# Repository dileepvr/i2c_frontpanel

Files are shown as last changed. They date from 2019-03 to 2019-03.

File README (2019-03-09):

---------------------------------------------------------------
i2c Frontpanel with 7-segment digits, pushbuttons, and two LEDs
---------------------------------------------------------------

Dumb frontpanel for small projects. Can be daisy-chained as long as
you do not populate all (except one) of the i2c pull-up resistors.

Powered by ATTiny88.

4-pin inter-header spacing is arduino compatible.

The PCBnew files are:

* 1x7seg_4btn.kicad_pcb (One 7-segment digit, four buttons, two LEDs)
* 2x7seg_4btn.kicad_pcb (Two 7-segment digits, four buttons, two LEDs)
* 4x7seg_6btn.kicad_pcb (Four 7-segment digits, six buttons, two LEDs)
* 4btn.kicad_pcb (Four buttons, two LEDs)
* 6btn.kicad_pcb (Six buttons, two LEDs)
* i2c_frontpanel.kicad_pcb (Same as 4x7seg_6btn.kicad_pcb)

Gerber files included for 4x7seg_6btn.kicad_pcb and
1x7seg_4btn.kicad_pcb designs.

The "firmware" folder contains the firmware for the ATTiny88.
Uses the ATTinyCore library: https://github.com/SpenceKonde/ATTinyCore

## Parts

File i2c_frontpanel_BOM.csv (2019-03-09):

Reference | Quantity | Value | Footprint | Part function | Mouser part # | Mouser link
AFF1 AFF2 AFF3 AFF4 | 4 | 7SEGMENTS | i2c_frontpanel:7seg_LTS_4817CKR_P | 7 segment digit | 859-LTS-4817CKR-P | https://www.mouser.com/ProductDetail/lite-on/lts-4817ckr-p/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
C1 C2 C3 C4 C5 C6 C7 C8 | 8 | 0.1uF | Capacitors_SMD:C_1206 | Capacitor | 710-885012208009 | https://www.mouser.com/ProductDetail/wurth-electronics/885012208009/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
CON1 | 1 | AVR-ISP-6-DR | Pin_Headers:Pin_Header_Straight_SMT_02x03 | 2x3 vertical smd header pins | 538-15-91-2060 | https://www.mouser.com/ProductDetail/molex/15-91-2060/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
D1 D2 | 2 | LED | LEDs:LED_1206 | Colored status LEDs | 743-S126ATG | https://www.mouser.com/ProductDetail/inolux/in-s126atg/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
IC1 | 1 | ATTINY88-A | Housings_QFP:TQFP-32_7x7mm_Pitch0.8mm | ATTINY88 Microcontroller | 556-ATTINY88-AUR | https://www.mouser.com/ProductDetail/microchip/attiny88-aur/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
Q1 Q2 Q3 Q4 Q5 Q6 | 6 | 2N7002 | TO_SOT_Packages_SMD:SOT-23 | N-MOSFET | 512-2N7002L | https://www.mouser.com/ProductDetail/on-semiconductor/2n7002l/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
R20 R21 | 2 | 4.7k | Resistors_SMD:R_1206 | Resistor | 603-RC0402FR-104K7L | https://www.mouser.com/ProductDetail/yageo/rc0402fr-104k7l/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
R22 R23 R24 R25 R26 R27 R28 R29 R30 R31 R32 R33 R34 R35 R36 R37 R38 R39 R40 R41 R42 R43 R44 R45 R46 R47 R48 R49 R50 R51 R52 R53 R54 R55 | 34 | 470 | Resistors_SMD:R_1206 | Resistor | 603-RC0402FR-13200RL | https://www.mouser.com/ProductDetail/yageo/rc0402fr-13200rl/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
R10 R11 R18 R19 R7 R8 | 6 | 100 | Resistors_SMD:R_1206 | Resistor | 603-RC0402FR-13200RL | https://www.mouser.com/ProductDetail/yageo/rc0402fr-13200rl/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
R1 R12 R13 R14 R15 R16 R17 R2 R3 R4 R5 R6 R9 | 13 | 10k | Resistors_SMD:R_1206 | Resistor | 667-ERJ-8ENF1002V | https://www.mouser.com/ProductDetail/panasonic/erj-8enf1002v/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
U1 | 1 | 74HC14D_653 | SMD_Packages:SOIC-14_N | Hex inverter buffer for debouncing | 771-74HC14D-T | https://www.mouser.com/ProductDetail/nexperia/74hc14d653/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
U10 U11 U12 U13 | 4 | MC14543B | SMD_Packages:SO-16-N | BCD-to-7-segment decoder | 863-MC14543BDR2G | https://www.mouser.com/ProductDetail/on-semiconductor/mc14543bdr2g/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
U2 U3 U4 U5 U6 U7 | 6 | SW_SPST | Resistors_SMD:R_2816 | Pushbuttons | 688-SKPSAAE010 | https://www.mouser.com/ProductDetail/alps/skpsaae010/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
U8 U9 | 2 | I2C_4PINS | Pin_Headers:Pin_Header_Straight_1x04 | Header pins | 649-68001-236HLF | https://www.mouser.com/ProductDetail/fci-amphenol/68001-236hlf/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

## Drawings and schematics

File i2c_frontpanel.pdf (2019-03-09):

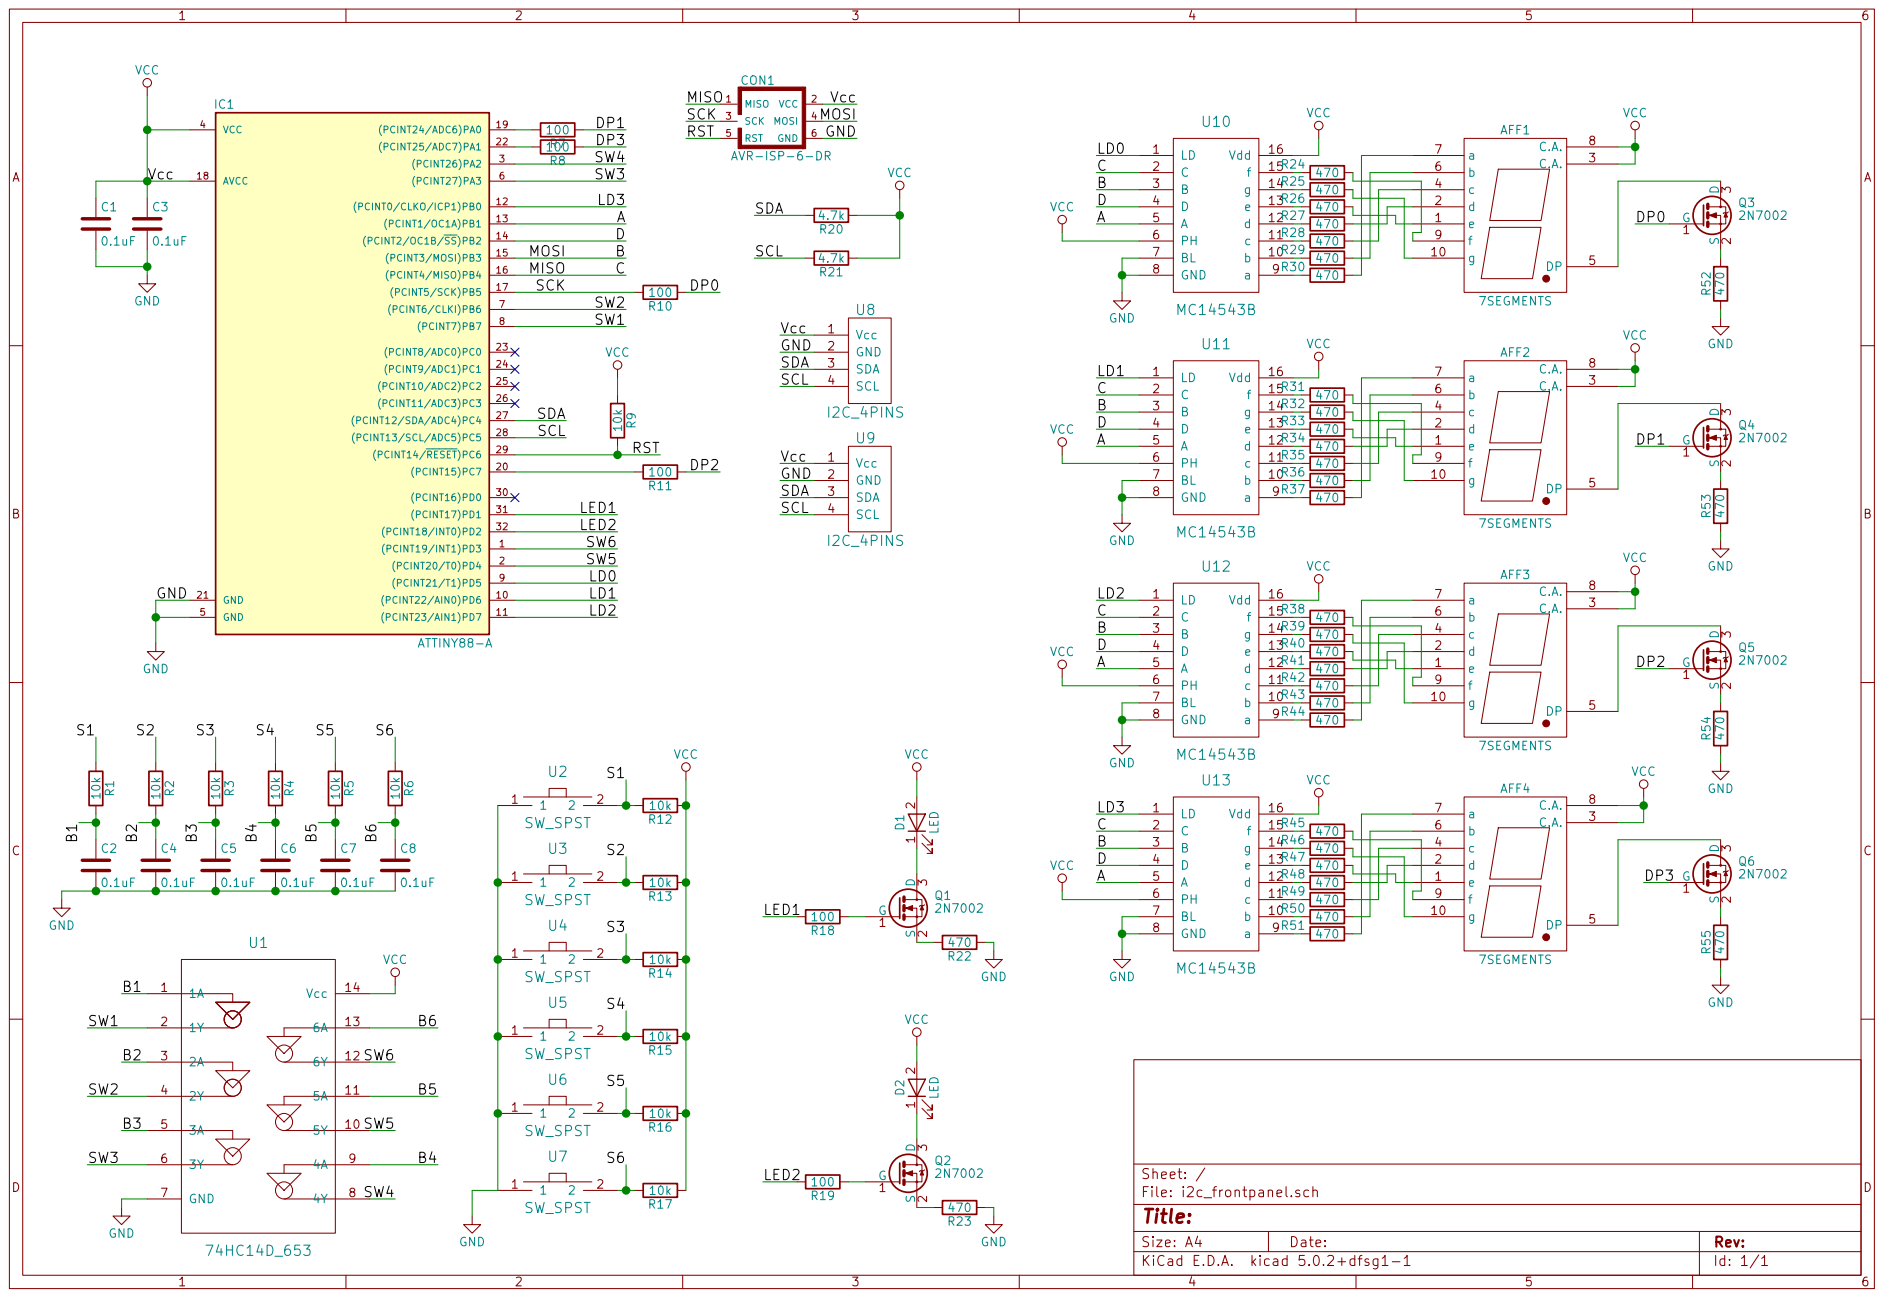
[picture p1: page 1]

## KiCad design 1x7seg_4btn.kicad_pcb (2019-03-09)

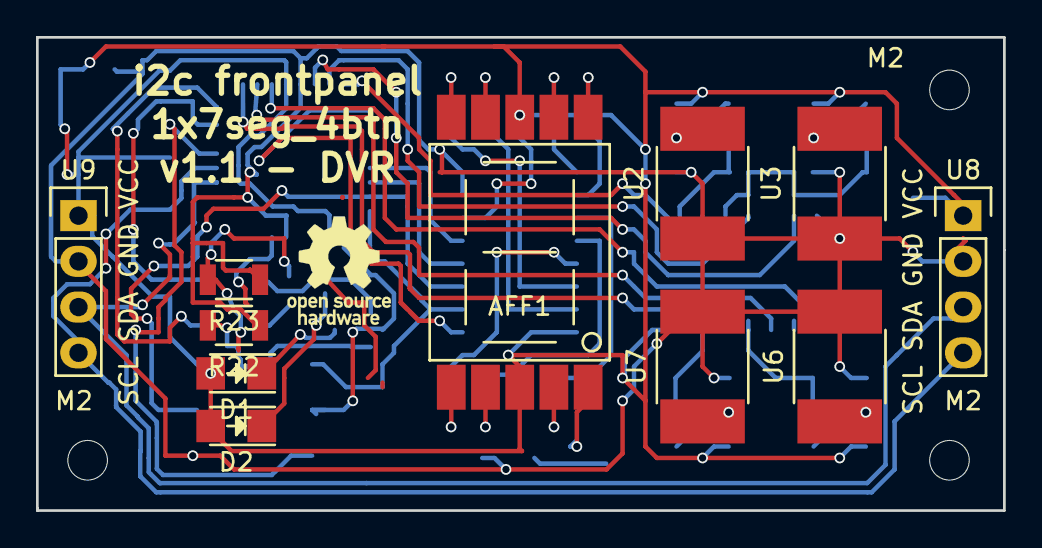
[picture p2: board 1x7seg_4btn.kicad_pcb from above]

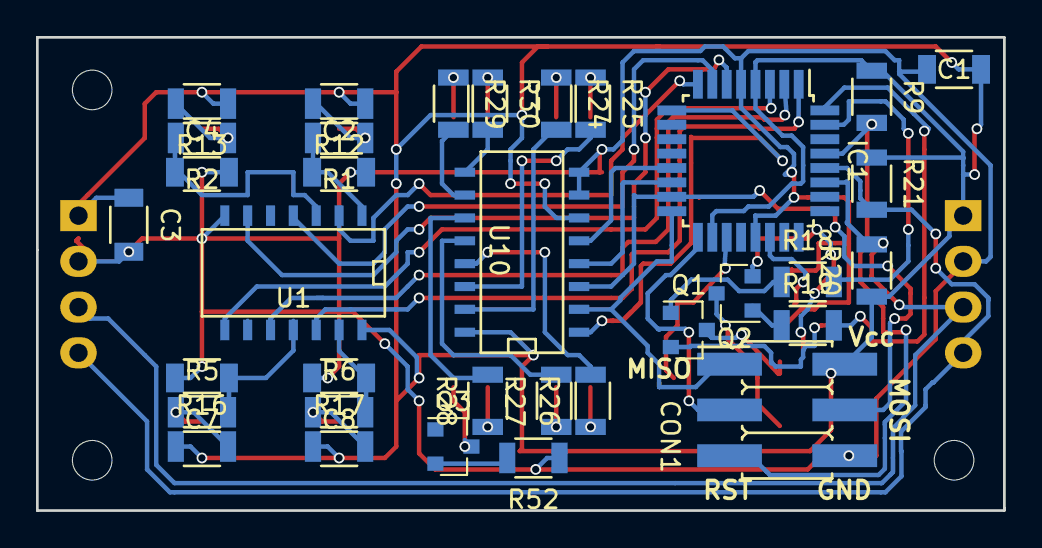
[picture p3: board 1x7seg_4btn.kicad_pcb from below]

Board: 2 copper layers, 53.7 x 26.3 mm, 45 parts (34 on the bottom side), 49 nets.

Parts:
AFF1: 7SEGMENTS; 7seg_LTS_4817CKR_P
C1, C2, C3, C4, C7, C8: 0.1uF; C_1206
CON1: AVR-ISP-6-DR; Pin_Header_Straight_SMT_02x03
D1, D2: LED; LED_1206
IC1: ATTINY88-A; TQFP-32_7x7mm_Pitch0.8mm
Q1, Q2, Q3: 2N7002; SOT-23
R1, R2, R5, R6, R9, R12, R13, R16, R17: 10k; R_1206
R18, R19: 100; R_1206
R20, R21: 4.7k; R_1206
R22, R23, R24, R25, R26, R27, R28, R29, R30, R52: 470; R_1206
U1: 74HC14D_653; SOIC-14_N
U2, U3, U6, U7: SW_SPST; R_2816
U8, U9: SCL SDA GND VCC; Pin_Header_Straight_1x04
U10: MC14543B; SO-16-N

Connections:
/A: IC1.13, U10.5
/B: CON1.4, IC1.15, U10.3
/B1: C2.1, R1.2, U1.1
/B2: C4.1, R2.2, U1.3
/B5: C7.1, R5.2, U1.11
/B6: C8.1, R6.2, U1.13
/C: CON1.1, IC1.16, U10.2
/D: IC1.14, U10.4
/LD0: IC1.9, U10.1
/LED1: IC1.31, R18.2
/LED2: IC1.32, R19.2
/RST: CON1.5, IC1.29, R9.2
/S1: R1.1, R12.2, U2.2
/S2: R2.1, R13.2, U3.2
/S5: R5.1, R16.2, U6.2
/S6: R6.1, R17.2, U7.2
/SCK: CON1.3, IC1.17
/SCL: IC1.28, R21.2, U8.4, U9.4
/SDA: IC1.27, R20.2, U8.3, U9.3
/SW1: IC1.8, U1.2
/SW2: IC1.7, U1.4
/SW3: IC1.6, U1.6
/SW4: IC1.3, U1.8
/SW5: IC1.2, U1.10
/SW6: IC1.1, U1.12
GND: C1.2, C2.2, C3.2, C4.2, C7.2, C8.2, CON1.6, IC1.5, IC1.21, R22.1, R23.1, R52.1, U1.7, U2.1, U3.1, U6.1, U7.1, U8.2, U9.2, U10.7, U10.8
unnamed: AFF1.1, R26.1
unnamed: AFF1.2, R27.1
unnamed: AFF1.4, R28.1
unnamed: AFF1.5, Q3.3
unnamed: AFF1.6, R29.1
unnamed: AFF1.7, R30.1
unnamed: AFF1.9, R24.1
unnamed: AFF1.10, R25.1
unnamed: D1.1, Q1.3
unnamed: D2.1, Q2.3
unnamed: Q1.1, R18.1
unnamed: Q1.2, R22.2
unnamed: Q2.1, R19.1
unnamed: Q2.2, R23.2
unnamed: Q3.2, R52.2
unnamed: R24.2, U10.15
unnamed: R25.2, U10.14
unnamed: R26.2, U10.13
unnamed: R27.2, U10.12
unnamed: R28.2, U10.11
unnamed: R29.2, U10.10
unnamed: R30.2, U10.9
VCC: AFF1.3, AFF1.8, C1.1, C3.1, CON1.2, D1.2, D2.2, IC1.4, IC1.18, R9.1, R12.1, R13.1, R16.1, R17.1, R20.1, R21.1, U1.14, U8.1, U9.1, U10.6, U10.16

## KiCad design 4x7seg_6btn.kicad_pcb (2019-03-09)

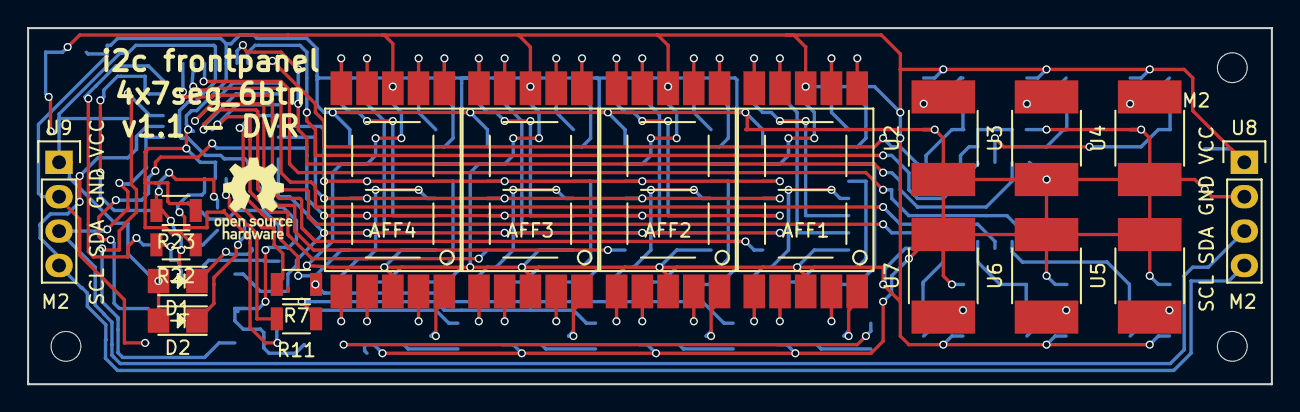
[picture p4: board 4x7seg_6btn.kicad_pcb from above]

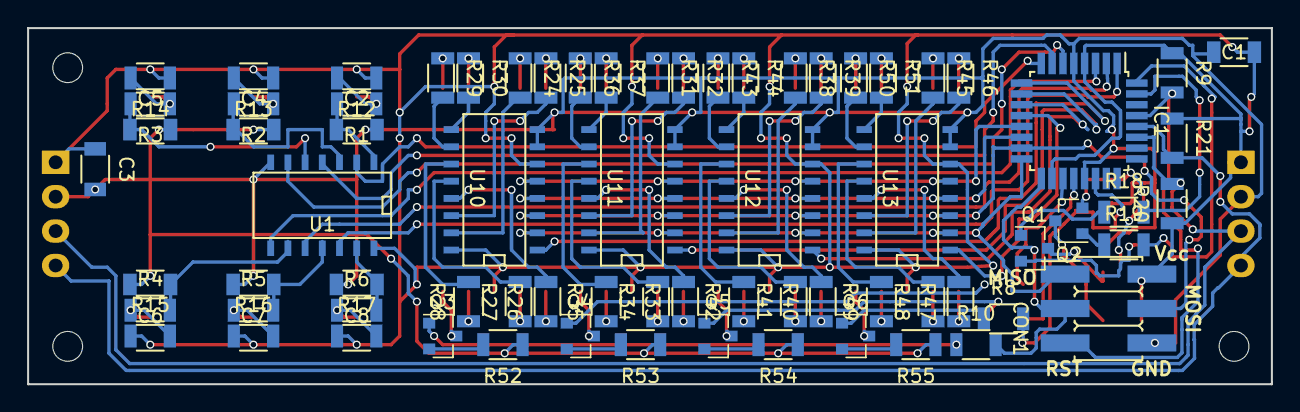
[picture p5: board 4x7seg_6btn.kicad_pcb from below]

Board: 2 copper layers, 91.8 x 26.3 mm, 90 parts (72 on the bottom side), 111 nets.

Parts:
AFF1, AFF2, AFF3, AFF4: 7SEGMENTS; 7seg_LTS_4817CKR_P
C1, C2, C3, C4, C5, C6, C7, C8: 0.1uF; C_1206
CON1: AVR-ISP-6-DR; Pin_Header_Straight_SMT_02x03
D1, D2: LED; LED_1206
IC1: ATTINY88-A; TQFP-32_7x7mm_Pitch0.8mm
Q1, Q2, Q3, Q4, Q5, Q6: 2N7002; SOT-23
R1, R2, R3, R4, R5, R6, R9, R12, R13, R14, R15, R16, R17: 10k; R_1206
R7, R8, R10, R11, R18, R19: 100; R_1206
R20, R21: 4.7k; R_1206
R22, R23, R24, R25, R26, R27, R28, R29, R30, R31, R32, R33, R34, R35, R36, R37, R38, R39, R40, R41, R42, R43, R44, R45, R46, R47, R48, R49, R50, R51, R52, R53, R54, R55: 470; R_1206
U1: 74HC14D_653; SOIC-14_N
U2, U3, U4, U5, U6, U7: SW_SPST; R_2816
U8, U9: SCL SDA GND VCC; Pin_Header_Straight_1x04
U10, U11, U12, U13: MC14543B; SO-16-N

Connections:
/A: IC1.13, U10.5, U11.5, U12.5, U13.5
/B: CON1.4, IC1.15, U10.3, U11.3, U12.3, U13.3
/B1: C2.1, R1.2, U1.1
/B2: C4.1, R2.2, U1.3
/B3: C5.1, R3.2, U1.5
/B4: C6.1, R4.2, U1.9
/B5: C7.1, R5.2, U1.11
/B6: C8.1, R6.2, U1.13
/C: CON1.1, IC1.16, U10.2, U11.2, U12.2, U13.2
/D: IC1.14, U10.4, U11.4, U12.4, U13.4
/DP0: Q3.1, R10.1
/DP1: Q4.1, R7.1
/DP2: Q5.1, R11.1
/DP3: Q6.1, R8.1
/LD0: IC1.9, U10.1
/LD1: IC1.10, U11.1
/LD2: IC1.11, U12.1
/LD3: IC1.12, U13.1
/LED1: IC1.31, R18.2
/LED2: IC1.32, R19.2
/RST: CON1.5, IC1.29, R9.2
/S1: R1.1, R12.2, U2.2
/S2: R2.1, R13.2, U3.2
/S3: R3.1, R14.2, U4.2
/S4: R4.1, R15.2, U5.2
/S5: R5.1, R16.2, U6.2
/S6: R6.1, R17.2, U7.2
/SCK: CON1.3, IC1.17, R10.2
/SCL: IC1.28, R21.2, U8.4, U9.4
/SDA: IC1.27, R20.2, U8.3, U9.3
/SW1: IC1.8, U1.2
/SW2: IC1.7, U1.4
/SW3: IC1.6, U1.6
/SW4: IC1.3, U1.8
/SW5: IC1.2, U1.10
/SW6: IC1.1, U1.12
GND: C1.2, C2.2, C3.2, C4.2, C5.2, C6.2, C7.2, C8.2, CON1.6, IC1.5, IC1.21, R22.1, R23.1, R52.1, R53.1, R54.1, R55.1, U1.7, U2.1, U3.1, U4.1, U5.1, U6.1, U7.1, U8.2, U9.2, U10.7, U10.8, U11.7, U11.8, U12.7, U12.8, U13.7, U13.8
unnamed: AFF1.1, R26.1
unnamed: AFF1.2, R27.1
unnamed: AFF1.4, R28.1
unnamed: AFF1.5, Q3.3
unnamed: AFF1.6, R29.1
unnamed: AFF1.7, R30.1
unnamed: AFF1.9, R24.1
unnamed: AFF1.10, R25.1
unnamed: AFF2.1, R33.1
unnamed: AFF2.2, R34.1
unnamed: AFF2.4, R35.1
unnamed: AFF2.5, Q4.3
unnamed: AFF2.6, R36.1
unnamed: AFF2.7, R37.1
unnamed: AFF2.9, R31.1
unnamed: AFF2.10, R32.1
unnamed: AFF3.1, R40.1
unnamed: AFF3.2, R41.1
unnamed: AFF3.4, R42.1
unnamed: AFF3.5, Q5.3
unnamed: AFF3.6, R43.1
unnamed: AFF3.7, R44.1
unnamed: AFF3.9, R38.1
unnamed: AFF3.10, R39.1
unnamed: AFF4.1, R47.1
unnamed: AFF4.2, R48.1
unnamed: AFF4.4, R49.1
unnamed: AFF4.5, Q6.3
unnamed: AFF4.6, R50.1
unnamed: AFF4.7, R51.1
unnamed: AFF4.9, R45.1
unnamed: AFF4.10, R46.1
unnamed: D1.1, Q1.3
unnamed: D2.1, Q2.3
unnamed: IC1.19, R7.2
unnamed: IC1.20, R11.2
unnamed: IC1.22, R8.2
unnamed: Q1.1, R18.1
unnamed: Q1.2, R22.2
unnamed: Q2.1, R19.1
unnamed: Q2.2, R23.2
unnamed: Q3.2, R52.2
unnamed: Q4.2, R53.2
unnamed: Q5.2, R54.2
unnamed: Q6.2, R55.2
unnamed: R24.2, U10.15
unnamed: R25.2, U10.14
unnamed: R26.2, U10.13
unnamed: R27.2, U10.12
unnamed: R28.2, U10.11
unnamed: R29.2, U10.10
unnamed: R30.2, U10.9
unnamed: R31.2, U11.15
unnamed: R32.2, U11.14
unnamed: R33.2, U11.13
unnamed: R34.2, U11.12
unnamed: R35.2, U11.11
unnamed: R36.2, U11.10
unnamed: R37.2, U11.9
unnamed: R38.2, U12.15
unnamed: R39.2, U12.14
unnamed: R40.2, U12.13
unnamed: R41.2, U12.12
unnamed: R42.2, U12.11
unnamed: R43.2, U12.10
unnamed: R44.2, U12.9
unnamed: R45.2, U13.15
unnamed: R46.2, U13.14
unnamed: R47.2, U13.13
unnamed: R48.2, U13.12
unnamed: R49.2, U13.11
unnamed: R50.2, U13.10
unnamed: R51.2, U13.9
VCC: AFF1.3, AFF1.8, AFF2.3, AFF2.8, AFF3.3, AFF3.8, AFF4.3, AFF4.8, C1.1, C3.1, CON1.2, D1.2, D2.2, IC1.4, IC1.18, R9.1, R12.1, R13.1, R14.1, R15.1, R16.1, R17.1, R20.1, R21.1, U1.14, U8.1, U9.1, U10.6, U10.16, U11.6, U11.16, U12.6, U12.16, U13.6, U13.16

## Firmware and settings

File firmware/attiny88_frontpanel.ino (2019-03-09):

/* https://github.com/SpenceKonde/ATTinyCore */
/* pinout https://github.com/SpenceKonde/ATTinyCore/blob/master/avr/extras/ATtiny_x8.md */

#include <Wire.h>

int led1 = 1; // PD1
int led2 = 2; // PD2
boolean led1_state = false;
boolean led2_state = false;

int BCD_A = 9; // PB1
int BCD_B = 11; // PB3
int BCD_C = 12; // PB4
int BCD_D = 10; // PB2
int BCD_DP = 13; // PB5
int BCD_L0 = 5; // PD5
int BCD_L1 = 6; // PD6
int BCD_L2 = 7; // PD7
int BCD_L3 = 8; // PB0

int SW1 = 15; // PB7
int SW2 = 14; // PB6
//int SW3 = 26; // PA3
int SW4 = 25; // PA2
int SW5 = 4; // PD4
int SW6 = 3; // PD3

int button_state = 0;

void setup() {
  // put your setup code here, to run once:
  pinMode(led1, OUTPUT);
  pinMode(led2, OUTPUT);
  pinMode(BCD_A, OUTPUT);
  pinMode(BCD_B, OUTPUT);
  pinMode(BCD_C, OUTPUT);
  pinMode(BCD_D, OUTPUT);
  pinMode(BCD_DP, OUTPUT);
  pinMode(BCD_L0, OUTPUT);
  pinMode(BCD_L1, OUTPUT);
  pinMode(BCD_L2, OUTPUT);
  pinMode(BCD_L3, OUTPUT);
  pinMode(SW1, INPUT);
  pinMode(SW2, INPUT);
  //pinMode(SW3, INPUT);
  pinMode(SW4, INPUT);
  pinMode(SW5, INPUT);
  pinMode(SW6, INPUT);
  digitalWrite(led1, LOW);
  digitalWrite(led2, LOW);
  digitalWrite(BCD_DP, LOW);
  digitalWrite(SW1, LOW);
  digitalWrite(SW2, LOW);
  //digitalWrite(SW3, LOW);
  digitalWrite(SW4, LOW);
  digitalWrite(SW5, LOW);
  digitalWrite(SW6, LOW);
  digit0(10, '0'); digit0(10, '1'); digit0(10, '2'); digit0(10, '3'); // Blank

  Wire.begin(8);
  Wire.onReceive(receiveEvent);
  Wire.onRequest(requestEvent); 
}

void loop() { 
  delay(100);
  if (readbuttons() != 0) {
    button_state = readbuttons();
  }
}

void digit0(int num, char digit) {  
  digitalWrite(BCD_A, bitRead(num,0));
  digitalWrite(BCD_B, bitRead(num,1));
  digitalWrite(BCD_C, bitRead(num,2));
  digitalWrite(BCD_D, bitRead(num,3));  

  switch (digit) {
    case '0':
      digitalWrite(BCD_L0, HIGH);  
      digitalWrite(BCD_L0, LOW);
      break;
    case '1':
      digitalWrite(BCD_L1, HIGH);  
      digitalWrite(BCD_L1, LOW);
      break;
    case '2':
      digitalWrite(BCD_L2, HIGH);  
      digitalWrite(BCD_L2, LOW);
      break;    
    default:
      digitalWrite(BCD_L3, HIGH);  
      digitalWrite(BCD_L3, LOW);
  }

}

int readbuttons() {
  int output = 0;
  if(digitalRead(SW1) == 1) { output = 1; }
  if(digitalRead(SW2) == 1) { output = 2; }
  //if(digitalRead(SW3) == 1) { output = 3; }
  if(digitalRead(SW4) == 1) { output = 4; }
  if(digitalRead(SW5) == 1) { output = 5; }
  if(digitalRead(SW6) == 1) { output = 6; }
  return output;
}

void receiveEvent(int howMany) {
  char ff = Wire.read();
  if(ff == 'L') {
    if (Wire.available()) {
      while (1 < Wire.available()) { // loop through all but the last
        char c = Wire.read(); // receive byte as a character
      }
      int x = Wire.read();    // receive byte as an integer       
      if(x == '1') {
        led1_state = ~led1_state;
        if(led1_state) {
          digitalWrite(led1, HIGH);
        } else {
          digitalWrite(led1, LOW);
        }        
      } else if(x == '2') {
        led2_state = ~led2_state;
        if(led2_state) {
          digitalWrite(led2, HIGH);
        } else {
          digitalWrite(led2, LOW);
        }        
      }      
    }
  } else {
    while (1 < Wire.available()) { // loop through all but the last
      char c = Wire.read(); 
    }
    int x = Wire.read();    // receive byte as an integer
    digit0(x, ff);    
  }
  
}

void requestEvent() {
  
    switch (button_state) {
      case 1:
        Wire.write('1');
        break;
      case 2:
        Wire.write('2');
        break;
      case 3:
        Wire.write('3');
        break;
      case 4:
        Wire.write('4');
        break;
      case 5:
        Wire.write('5');
        break;
      case 6:
        Wire.write('6');
        break;        
      default:
        Wire.write('0');
    }
    button_state = 0;

}

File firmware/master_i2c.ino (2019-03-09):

#include <Wire.h>

void setup() {
  // put your setup code here, to run once:
  Wire.begin();
  Serial.begin(115200);
}

void loop() {
  // put your main code here, to run repeatedly:
  delay(100);

  char p;
  if(Serial.available() > 0) {
    p = Serial.read();
    if(p == 'B') {
      Wire.requestFrom(8, 1);    // request 1 byte from slave device #8

      if(Wire.available()) {
        Serial.print("Received: ");
        while (Wire.available()) { // slave may send less than requested
          char c = Wire.read(); // receive a byte as character
          Serial.print(c);         // print the character
        }
        Serial.println();
      }
    } else if (p != '\n') {
      Wire.beginTransmission(8);
      Wire.write(p);
      while(Serial.available() > 0) {
        char c = Serial.read();
        if(c != '\n') {
          //Wire.beginTransmission(8);
          Wire.write(c);
          //Wire.endTransmission();
          //Serial.write(c);    
        }
      }
      Wire.endTransmission();
      Serial.println("Sent.");
    }
  }

}

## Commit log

2018-09-01 major components are in the schematic
    [i2c_frontpanel.kicad_pcb, i2c_frontpanel.sch]
2018-09-03 Schematic done.
    [i2c_frontpanel.sch]
2018-09-05 Footprints done. LICENSE now CERN open hardware license.
    [i2c_frontpanel.sch]
2018-09-08 PCB routing done.
    [i2c_frontpanel.kicad_pcb]
2018-09-10 gerbers done.
    [1x7seg_4btn-B.Adhes.gbr, 1x7seg_4btn-B.Cu.gbr, 1x7seg_4btn-B.Mask.gbr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]
2018-09-10 Moved oshw logo
    [1x7seg_4btn-B.Adhes.gbr, 1x7seg_4btn-B.Cu.gbr, 1x7seg_4btn-B.Mask.gbr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]
2018-09-10 Moved header pins on 1x7seg_4btn version to match height on both sides
    [1x7seg_4btn-B.Adhes.gbr, 1x7seg_4btn-B.Cu.gbr, 1x7seg_4btn-B.Mask.gbr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]
2018-09-11 Headers aligned better
    [1x7seg_4btn-B.Adhes.gbr, 1x7seg_4btn-B.Cu.gbr, 1x7seg_4btn-B.Mask.gbr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]
2018-09-11 Added new pcb layouts
2018-09-22 Added BOM. Moved i2c pin designations to silkscreen.
    [1x7seg_4btn-B.Adhes.gbr, 1x7seg_4btn-B.Cu.gbr, 1x7seg_4btn-B.Mask.gbr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]
2019-03-09 v1.1 fixed 74HC14 bottom-row button pin mappings.
    [1x7seg_4btn-B.Adhes.gbr, 1x7seg_4btn-B.Cu.gbr, 1x7seg_4btn-B.Mask.gbr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]
2019-03-09 Added AttinyCore fimrware and i2c_master firmware for testing.
2019-03-09 Firmare and README file added
    [i2c_frontpanel_BOM.csv]
